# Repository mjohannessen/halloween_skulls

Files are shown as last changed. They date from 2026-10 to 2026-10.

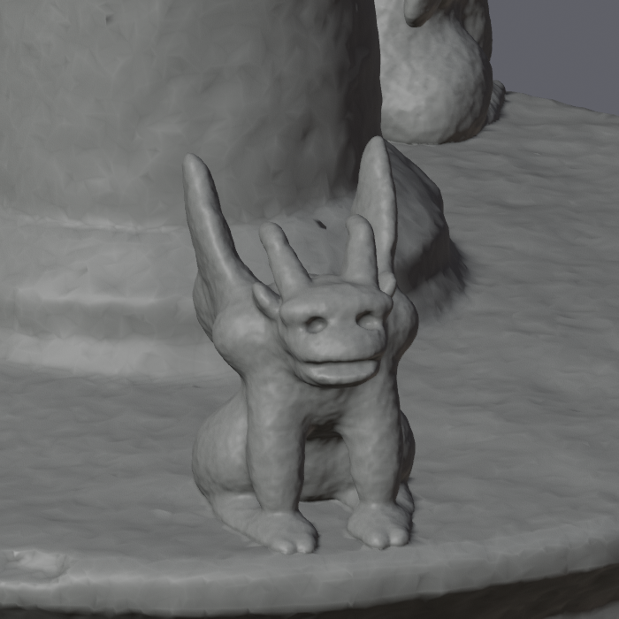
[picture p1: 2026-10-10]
halloween-skull/renders/base_gargoyle.png

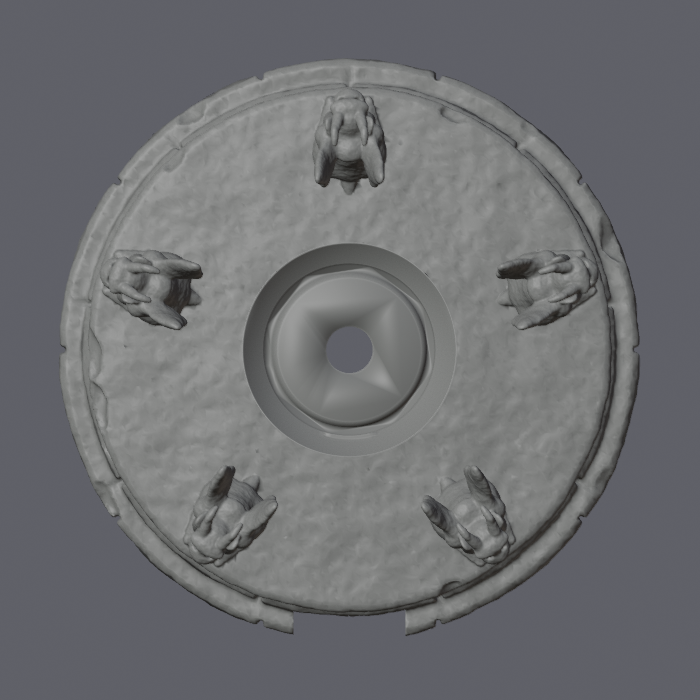
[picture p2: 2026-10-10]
halloween-skull/renders/base_top.png

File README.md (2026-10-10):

# halloween_skulls

3D-printed Halloween ornaments lit by 5V NeoPixels, driven from one control box and controlled from openHAB.

The control box holds a Raspberry Pi Pico W. It has a power input and one output connector, which carries 5V, GND and data out to a chain of **ornaments**. Each ornament has an input and an output connector and holds one or more 5V NeoPixels. Ornaments plug into each other in any order and any mix, and all their LEDs form one NeoPixel chain:

```
control box ─► ornament 1 ─► ornament 2 ─► … ─► ornament N (output unused)
```

The first set of ornaments is three skulls with one LED each:

```
control box ─► skull 1 (1 LED) ─► skull 2 (1 LED) ─► skull 3 (1 LED)
```

## Control box

### Power

The box runs from either a 5V wall brick or a 5V battery pack. Both have DC5521 (5.5 × 2.1 mm) plugs and share one panel jack, one at a time. The Pico's micro-USB stays reachable for flashing.

```
DC jack + ──┬── chain output 5V (1000 µF across 5V / GND)
            │
            ├── 1N5817 Schottky ─────────────────────┬── Pico VSYS ── 74AHCT125 VCC
            │                                        │
            │   micro-USB ── VBUS ── Pico's onboard diode ──┘
            │
            └── 10 kΩ ──┬── GP28 (supply sense)
                        └── 15 kΩ ── GND

DC jack − ── GND (common to the Pico, shifter and chain output)
```

- **The LEDs run straight from the DC jack**, not through the Pico, so the chain's current doesn't pass through the Pico or the diode.
- **The Pico runs from VSYS**, fed through diodes from the jack and from USB. Both can be connected at once without either back-feeding the other. VSYS sits at about 4.7V either way (5V less one diode drop).
- **USB alone doesn't power the chain.** USB is for flashing, so a laptop's USB port never has to supply the LEDs.
- **Supply sense:** a 10 kΩ / 15 kΩ divider puts about 3.0V on GP28 when the jack has power, and the 15 kΩ pulls it to 0V when it doesn't. On USB alone the shifter is still powered from VSYS but the chain isn't, so a high on the data line would feed current into the first LED's data input. The firmware reads GP28 and holds GP0 low unless the jack has power.

### Data

```
Pico GP0 ── 74AHCT125 1A → 1Y ── 330 Ω ── chain output DATA
```

The 74AHCT125 shifts the Pico's 3.3V data up to VSYS, about 4.7V, because 3.3V is below the LEDs' 0.7 × 5V = 3.5V input threshold. Only channel 1 is used. The 330 Ω resistor sits at the shifter's output and protects the first LED's data input.

### Wiring list

Every connection in the box, grouped by net. Pico pin numbers are the physical pins (pin 1 is GP0, next to the USB connector). Do **not** connect anything to the Pico's VBUS (pin 40); the jack feeds VSYS only, through the diode.

| Net | Connects |
|---|---|
| **5V (jack)** | DC jack + (centre pin) · 1N5817 anode · 10 kΩ · 1000 µF + leg · JST output red (5V) |
| **VSYS** | 1N5817 cathode (banded end) · Pico pin 39 (VSYS) · 74AHCT125 pin 14 (VCC) · pin 4 (2OE) · pin 10 (3OE) · pin 13 (4OE) · 0.1 µF |
| **GND** | DC jack − (sleeve) · Pico pin 38 (GND) · 74AHCT125 pin 7 (GND) · pin 1 (1OE) · pin 5 (2A) · pin 9 (3A) · pin 12 (4A) · 15 kΩ · 1000 µF − leg (striped side) · 0.1 µF · JST output GND |
| **Sense** | 10 kΩ · 15 kΩ · Pico pin 34 (GP28 / ADC2) |
| **Data in** | Pico pin 1 (GP0) · 74AHCT125 pin 2 (1A) |
| **Data out** | 74AHCT125 pin 3 (1Y) · 330 Ω |
| **Chain DATA** | 330 Ω · JST output DATA |

74AHCT125 pins 6 (2Y), 8 (3Y) and 11 (4Y) are outputs and stay unconnected. Its enables are active-low, so 1OE to GND turns channel 1 on and 2OE–4OE to VCC turn the unused channels off. The unused inputs go to GND so they don't float.

Build notes:

- **Placement:** the 0.1 µF goes right at the shifter's pins 14 and 7. The 1000 µF goes where the jack and the JST output wires land on the perfboard, so the chain's current doesn't run through the shifter's ground.
- **Wire gauge:** the jack-to-output 5V and GND carry the whole chain's current (up to 2 A on the 2 A brick), so use 22 AWG there. The Pico and signal wires can be thinner.
- **Wires to the Pico:** with the Pico's USB end at the back wall and its pins facing up, pins 34, 38 and 39 are on the edge facing the perfboard. GP0 (pin 1) is on the edge against the side wall, so its wire crosses the USB end of the board.
- **Checks before plugging in ornaments:** with only the jack connected, measure about 5V at the JST output's 5V/GND, about 4.7V at VSYS and at the shifter's pin 14, and about 3.0V at GP28. With only USB connected, the JST output's 5V should read 0V.

## Chain connector

Every connection in the chain is a **JST-SM 3-pin** pigtail pair, the standard WS2812 string connector:

| Wire | Signal |
|---|---|
| Red | 5V |
| Green (or white) | DATA |
| White (or black) | GND |

Wire colours vary between batches. Check the pairs you buy, then use the same pin order everywhere.

- The **box output** and every **ornament output** use the **female** (socket) half, so the live 5V pins are recessed and can't short against anything.
- Every **ornament input** uses the **male** (pin) half.

Any ornament can then plug into the box or into any other ornament. The last ornament's output is still live, so leave its cap on or tape it.

## Ornaments

An ornament is any housing with an input pigtail, one or more 5V NeoPixels in a chain, and an output pigtail:

```
input 5V ───────┬──────────┬──────────────── output 5V
input GND ──────┼────┬─────┼────┬─────────── output GND
input DATA ── DIN LED 1 DOUT ── DIN LED 2 DOUT ── … ── output DATA
            0.1 µF across each LED's 5V / GND
```

- Through-hole NeoPixels (5 mm or 8 mm, WS2812D / PL9823 type) need a 0.1 µF ceramic capacitor across each LED's 5V and GND pins. They have no onboard decoupling. NeoPixels on a PCB or strip already have it.
- 5V and GND run straight through the ornament to its output, so every ornament gets power from the same pair.

### Skull ornament

One 5 mm through-hole NeoPixel sits in the skull's cavity behind the eyes, and its glow comes out through both eye sockets. The input and output pigtails leave through the 18 mm opening in the skull's base.

The skull model (`halloween-skull/build_skull.py`) needs no changes for this. The LED goes in through the base opening, and its light reaches both eyes through the eye-socket bores that open into the cavity.

Each skull sits on a weathered cemetery-stone base (`halloween-skull/build_base.py`, which writes `base.stl`, `base.blend` and `renders/base_*.png` / `assembly_*.png`):

- **Pedestal:** round, 62 mm across and 28.5 mm tall. It has two stepped base courses cut into staggered blocks with mortar joints, a drum with a Gothic lancet niche on each of its four sides, and a projecting cap stone sloping up to the stem. Five crouching winged gargoyles (about 13 mm tall) sit on the cap stone ledge facing outward, one at the front; `GARGOYLES`, `GARGOYLE_R` and `GARGOYLE_SCALE` set their number, position and size. `renders/base_gargoyle.png` is a close-up of one.
- **Stem:** a 20 mm stout stone column on a chamfered base block, flaring at 45° into the seat.
- **Weathering:** the stone is voxel-remeshed and displaced with two scales of noise, and its upper edges are chipped. `SEED` sets the chip pattern, so each skull's base can be different. `WEATHER` sets how rough the surface is. The seat, spigot and wire path are added after weathering, so they stay exact.
- **Seat:** 23 mm across. The skull's underside isn't flat: around its opening it rises from 0.7 mm above the chin plane at the front to about 5 mm at the back. So the seat is cut from the skull model itself (with 0.2 mm clearance for glue) and supports the whole underside. A 16.6 mm spigot, 6 mm tall, fits up into the skull's ~17 mm opening and centres it.
- **Wires:** a 5 mm hole runs down the centre, sized for the LED's four 22 AWG wires (5V, GND, DIN, DOUT), which are glued in place to position the LED inside the skull. Underneath is a 45° cone-shaped cavity for splicing them to the input and output JST pigtails. The pigtails leave through a 12 × 6 mm notch at the back.
- **Printing:** print it as modelled, plinth on the bed, with no supports. Every overhang is 45° or steeper, and the niche tops are pointed arches.

The seat is cut from `skull.blend`, so run `build_skull.py` first if the skull changes, then `build_base.py`:

```sh
Blender -b -P build_skull.py -- <output_dir>
Blender -b -P build_base.py -- <output_dir>
```

Dimensions are mm parameters at the top of `build_base.py`.

## Firmware chain layout

The firmware needs to know which ornaments are in the chain, in order from the box, and how many LEDs each has. It keeps this as a list:

```python
CHAIN = [
    ("skull", 1),
    ("skull", 1),
    ("skull", 1),
]
```

The total LED count is the sum of the counts. Effects address ornaments by position in the list, so a mixed chain needs only this list changed, with no change to the effect code. The plan is to make the layout settable over MQTT, so rearranging ornaments doesn't need a reflash.

## Current budget

Each NeoPixel draws up to about 60 mA at full white and about 20 mA for one colour at full brightness. The firmware should cap brightness so the whole chain stays inside the supply.

| Chain | Worst case (full white) |
|---|---|
| 3 skulls × 1 LED | 0.18 A |
| 20 LEDs | 1.2 A |
| 40 LEDs | 2.4 A |

JST-SM connectors and 22 AWG chain wire are good for about 3 A. Above roughly 30 LEDs, or for long cable runs, inject 5V and GND part way along the chain rather than through every connector.

## Parts list

### Control box

| Part | Qty | Notes |
|---|---|---|
| Raspberry Pi Pico W | 1 | Solder wires directly to it rather than fitting headers |
| 74AHCT125 level shifter, DIP-14 | 1 | 3.3V → 5V data. The wiring list uses its DIP-14 pin numbers |
| 330 Ω resistor | 1 | In series with the data line, at the shifter output |
| 1N5817 (or SS14) Schottky diode | 1 | DC jack + → VSYS |
| 10 kΩ and 15 kΩ resistors | 1 each | Supply-sense divider to GP28 |
| 1000 µF 10V electrolytic capacitor | 1 | Across 5V / GND at the chain output, absorbs inrush when ornaments are plugged in |
| 0.1 µF ceramic capacitor | 1 | Across the 74AHCT125's VCC / GND |
| Perfboard | 1 | Holds the shifter, resistors, diode and capacitors |
| DC5521 (5.5 × 2.1 mm) female panel-mount barrel jack | 1 | Power input. The same jack as lr_light: 10.75 mm thread in an 11.2 mm hole |
| JST-SM 3-pin female pigtail | 1 | Chain output, through the box wall |
| M3 heat-set inserts and M3 × 6 mm screws | 4 each | Lid to corner posts |
| M2 self-tapping screws, ~5 mm | 4 | Pico W to its standoffs |
| Small zip tie | 1 | Anchors the output pigtail inside the box |

### Power

| Part | Qty | Notes |
|---|---|---|
| 5V wall brick, DC5521 plug, ≥2 A | 1 | 2 A covers about 30 LEDs at full white |
| KBT 5V 8 Ah lithium-ion battery pack (DC5521 lead) | 1 | Battery power, as an alternative to the brick. It has a built-in boost converter, so it gives a regulated 5V. Three skulls glowing red (~60 mA plus the Pico) run for days per charge. Charge it with its own charger |
| DC5521 extension lead, male–female | as needed | If the brick's or battery's lead doesn't reach |

### Per skull ornament

| Part | Qty | Notes |
|---|---|---|
| 5 mm through-hole NeoPixel (WS2812D-F5 / PL9823-F5 type) | 1 | Diffused lens looks best |
| 0.1 µF ceramic capacitor | 1 | Across the LED's 5V / GND pins |
| JST-SM 3-pin pigtail pair | 1 | The male half is the input, the female half the output |
| Heat-shrink tubing | — | For the LED leg joints |

### Chain

| Part | Qty | Notes |
|---|---|---|
| JST-SM 3-pin extension lead | as needed | Between ornaments that sit further apart than their pigtails reach |

## Enclosure (`cad/`)

### Control box

`cad/control_box.FCStd` is the control box and its lid. The box is 88.8 × 77 mm outside and 29 mm tall with the lid on. Every dimension is a cell in the document's `Params` spreadsheet, so edit a cell and press Recompute.

- **Inside:** the Pico W sits on four 5 mm standoffs along the left side, with M2 self-tapping screws. The perfboard sits beside it in a floor cradle, 4 mm up for solder-joint clearance, with no screws.
- **Back wall:** everything plugs in here: the micro-USB slot at the Pico's USB end, the DC jack (11.2 mm hole) and a 5 mm hole for the JST-SM output pigtail's wires. A zip-tie anchor on the floor behind the pigtail hole takes the pull off the solder joints.
- **Lid:** a flat plate whose lip drops 3 mm inside the walls to locate it. Four M3 screws hold it on, through counterbored holes into heat-set inserts in the corner posts.
- **Printing:** print the body open side up and the lid flat face down, both without supports.

| File | What it is |
|---|---|
| `control_box.FCStd` | **The model, edit this.** `Control_box_body` and `Control_box_lid` are the printed parts. The `Components` group holds placeholders (Pico, perfboard, jack, pigtail) for checking fit and isn't printed |
| `stl/control_box_body.stl`, `stl/control_box_lid.stl` | Ready-to-print exports. After editing, re-export with File → Export on each part |
| `control_box.py` | Generates the `.FCStd` from scratch. It only overwrites with `SKULL_OVERWRITE=1 freecadcmd control_box.py`, so hand edits aren't lost |

The perfboard size (48.3 × 44.5 mm), the jack's thread (10.75 mm), its body length inside the box (10 mm) and its nut (14 mm) are measured. The perfboard's components are taken as 12 mm tall (`PERF_H`, with the 1000 µF capacitor lying on its side), which leaves about 6 mm under the lid for wiring. Check them against the built board before printing.

### Earlier two-skull design

`cad/skull_bases.FCStd` and `cad/skull_bases.py` are the earlier design: a control base under the master skull, a stand for the second skull and a JST link between them. The control box and the cemetery-stone skull bases replace them. Only the battery box (`Battery_box_body` / `Battery_box_lid`) is still useful.

## Planned: low-battery alert

The battery pack's boost converter holds its output at 5V until the cells are nearly empty and then cuts off. Measuring the supply voltage gives no warning, and the Pico can't tell the battery from the wall brick, since both supply a regulated 5V through the same jack. So:

- **Power source:** openHAB holds a switch (e.g. `Skulls_On_Battery`) that you turn on when the battery is plugged in, and the firmware reads it over MQTT.
- **Charge estimate:** while on battery, the firmware adds up runtime weighted by LED count and brightness against the pack's ~30 Wh. It saves the total to flash every few minutes so it survives restarts. Turning `Skulls_On_Battery` back on after a recharge resets the counter.
- **MQTT:** it publishes something like `skulls/status {"power":"battery","batt_hours":18.5,"batt_pct":62}`. Its last will publishes `offline` on the same topic, following led_flowerpot's command/reply/status pattern.
- **openHAB:** at about 20% left, a rule pushes an ntfy alert. If the skulls go offline while on battery, it pushes "Skulls offline — battery probably dead".

If the estimate turns out to be unreliable, an INA219 current sensor in the control box can measure the mAh actually used.

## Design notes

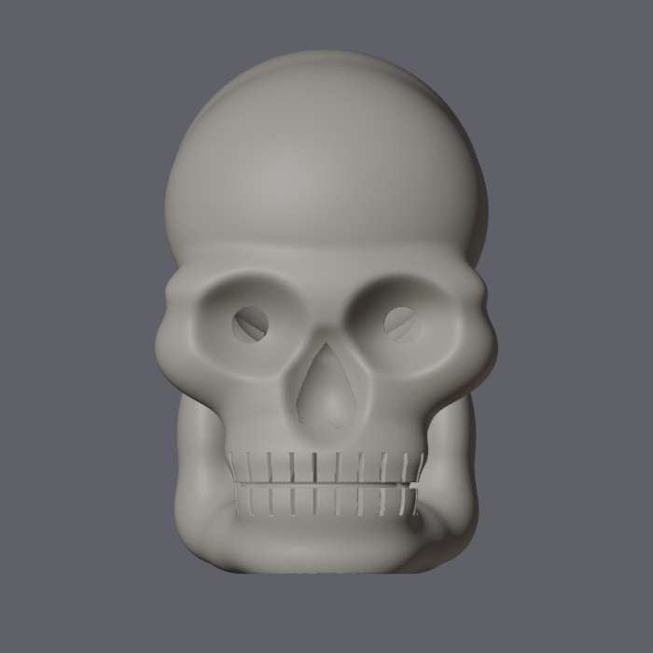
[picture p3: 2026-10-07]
halloween-skull/renders/front.png

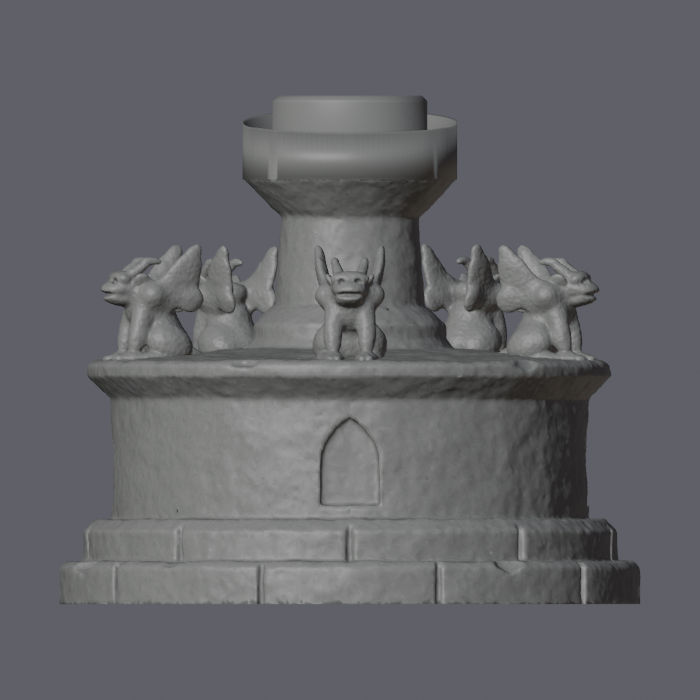
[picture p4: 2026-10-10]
halloween-skull/renders/base_front.png

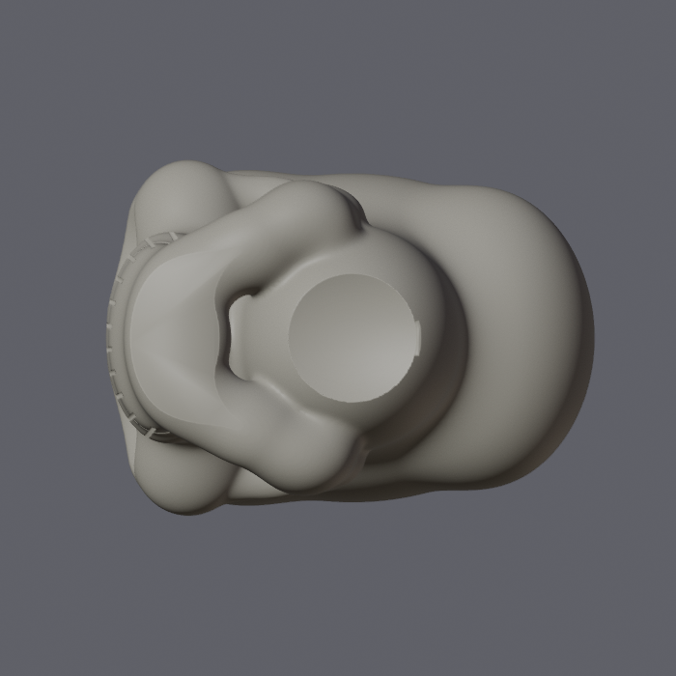
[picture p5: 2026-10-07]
halloween-skull/renders/bottom.png

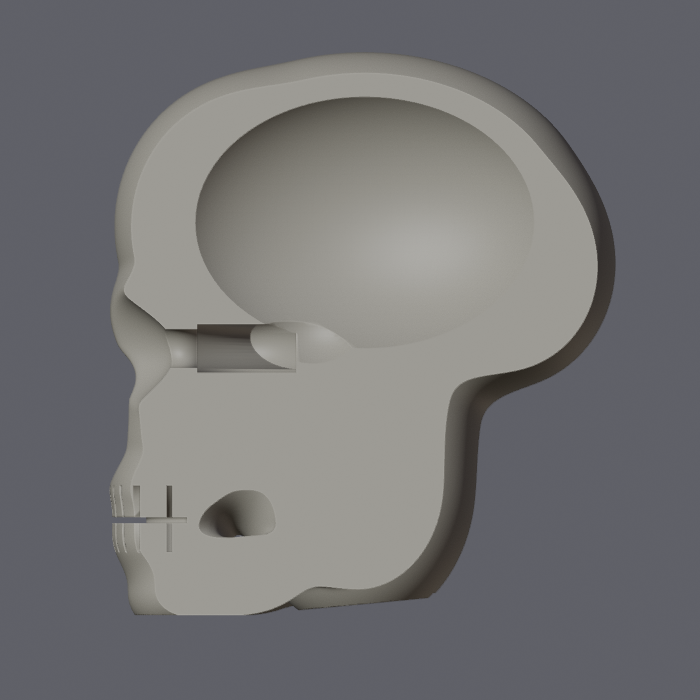
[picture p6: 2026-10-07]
halloween-skull/renders/section_eye.png

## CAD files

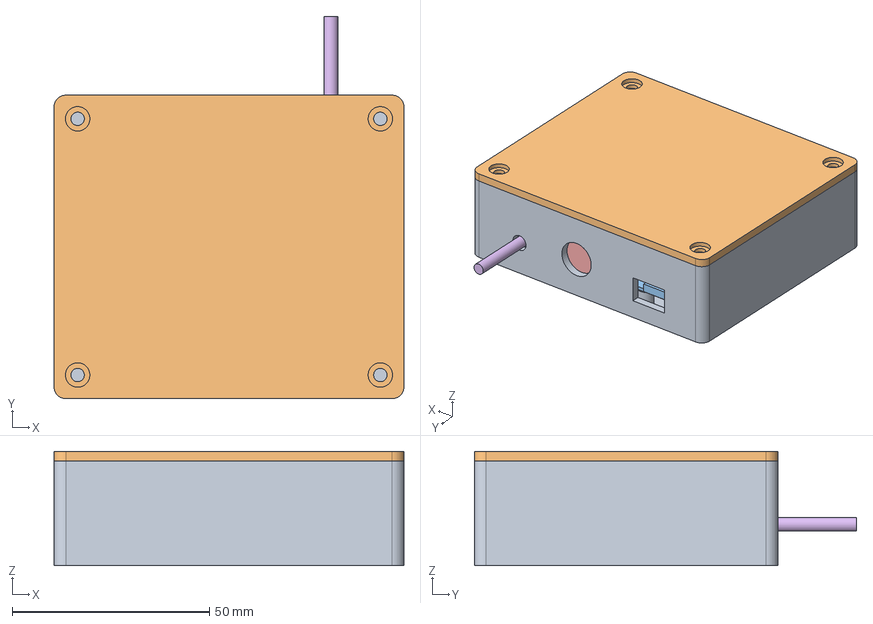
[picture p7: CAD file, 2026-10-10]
cad/control_box.FCStd
88.8 x 97.0 x 29.0 mm
Control_box_body
Control_box_lid
Pico_W
Perfboard
DC_jack
Output_pigtail

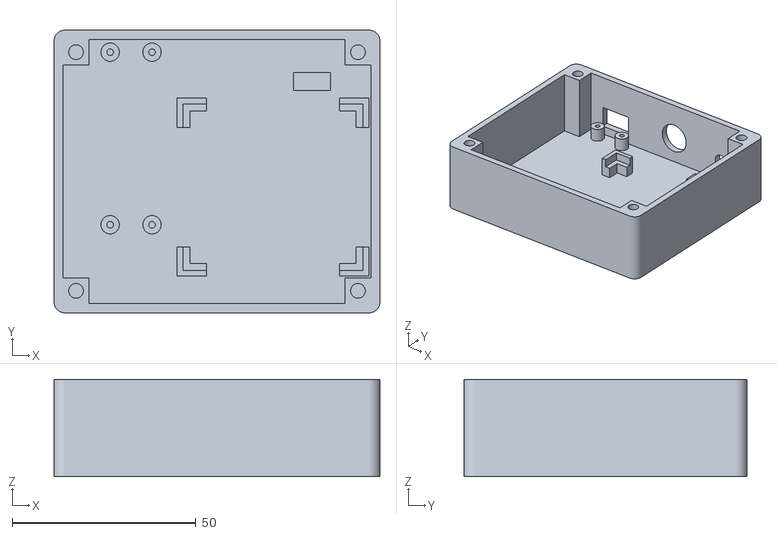
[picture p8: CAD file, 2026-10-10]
cad/stl/control_box_body.stl
88.8 x 77.0 x 26.5

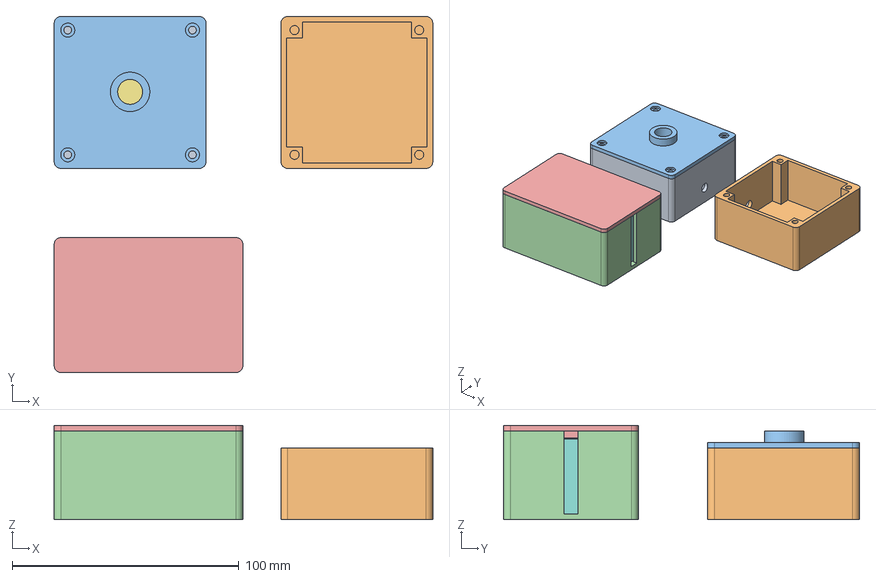
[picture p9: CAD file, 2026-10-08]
cad/skull_bases.FCStd
167.0 x 157.0 x 41.5 mm
Control_base_body
Stand_body
Lid
Battery_box_body
Battery_box_lid
Pico_W
Perfboard
Battery_pack

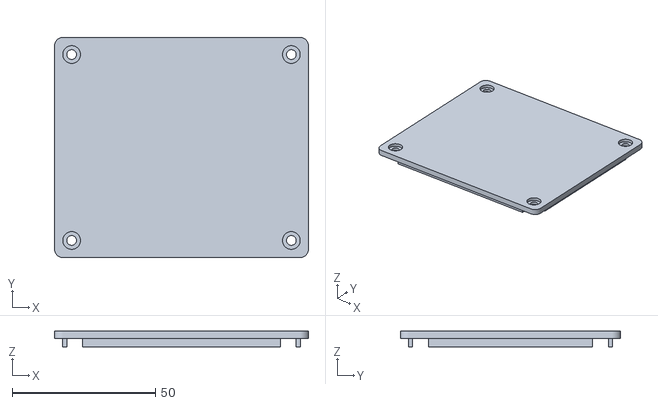
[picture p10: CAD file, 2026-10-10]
cad/stl/control_box_lid.stl
88.8 x 77.0 x 5.50

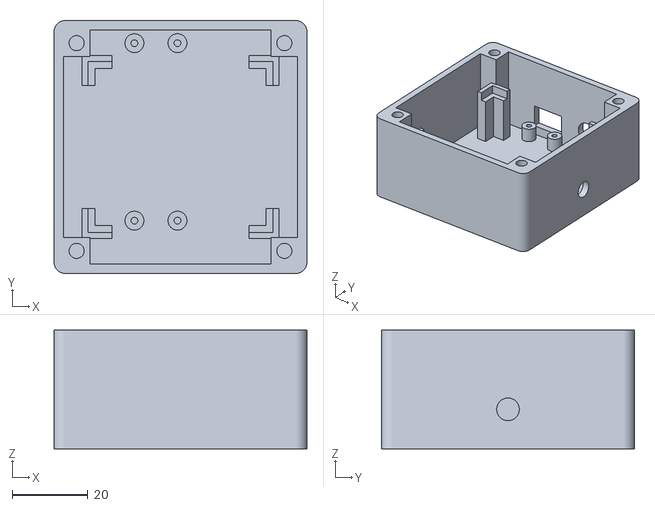
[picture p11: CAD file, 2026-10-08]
cad/stl/control_base_body.stl
67.0 x 67.0 x 31.5

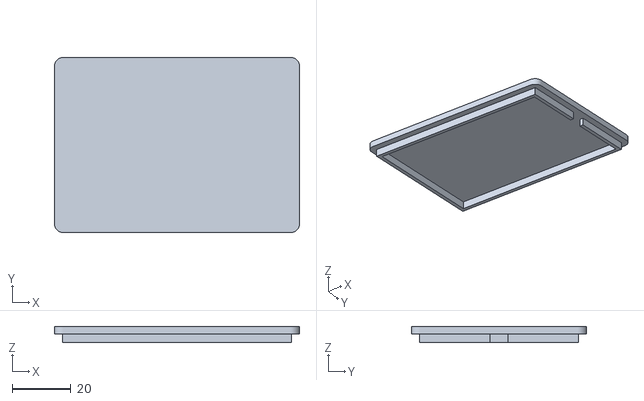
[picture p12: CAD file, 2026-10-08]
cad/stl/battery_box_lid.stl
83.2 x 59.5 x 5.50

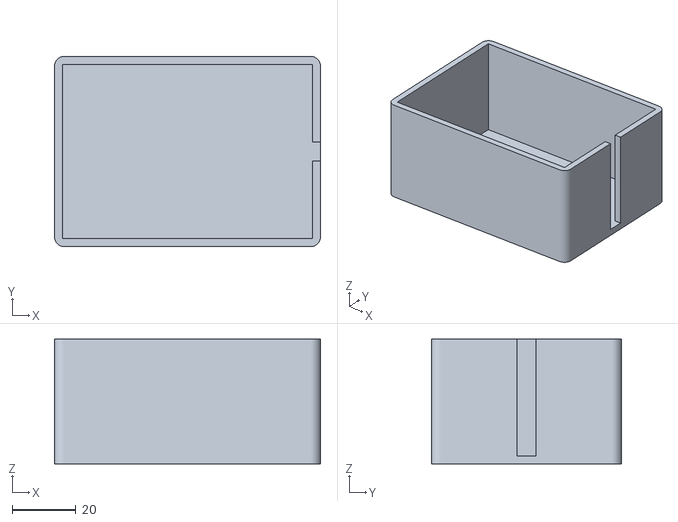
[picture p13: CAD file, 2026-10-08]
cad/stl/battery_box_body.stl
83.2 x 59.5 x 39.0

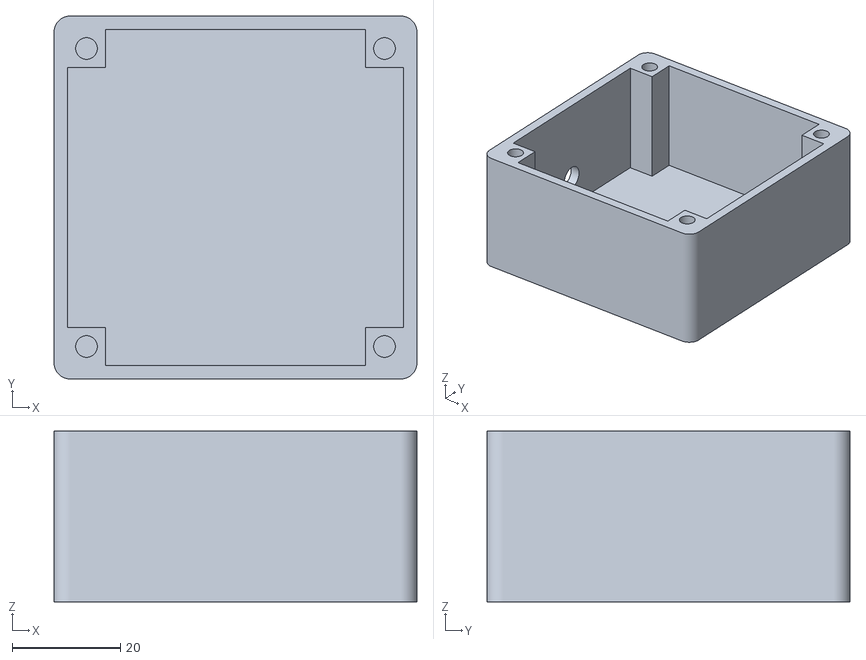
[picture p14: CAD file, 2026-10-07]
cad/stl/stand_body.stl
67.0 x 67.0 x 31.5

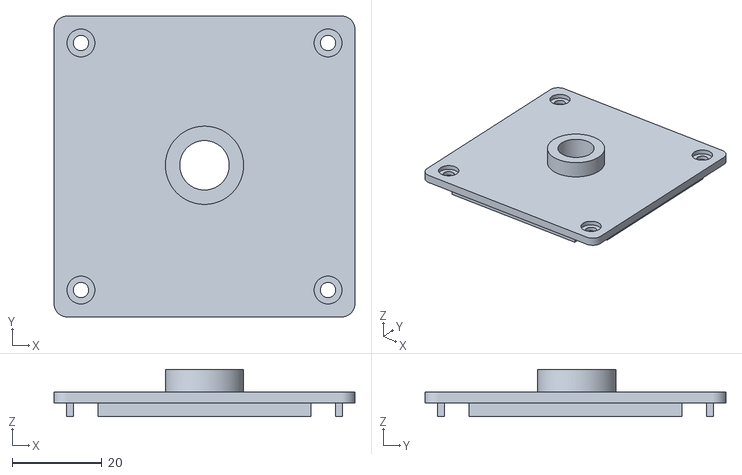
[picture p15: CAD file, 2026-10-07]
cad/stl/lid_x2.stl
67.0 x 67.0 x 10.5

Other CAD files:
halloween-skull/base.blend
halloween-skull/skull.blend

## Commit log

2026-10-07 Add procedural skull model (Blender script, .blend, STL, renders)
    [skull.blend]
2026-10-07 Parametric FreeCAD bases: control base (Pico W), second-skull stand, lid with locating tube
    One Pico W drives all four eyes; a 3-pin JST link carries 5V/GND/data
    to the second skull. README parts list updated for that layout.
    [control_base_body.stl, lid_x2.stl, skull_bases.FCStd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]
2026-10-07 Stack the 48.3 x 44.5 mm perfboard above the Pico W
    Raised corner-bracket cradle centred in the control base, Pico moved
    right to clear it, inside height 24 -> 29 mm. STLs regenerated.
    [control_base_body.stl, lid_x2.stl, skull_bases.FCStd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]
2026-10-08 Battery power: DC5521 jack in the control base, battery box
    The control base takes either USB or a 5 V 8 Ah pack through a back-wall
    DC5521 jack; the pack feeds VSYS via a Schottky diode and the LEDs move
    from VBUS to VSYS. New friction-fit battery box with a lead slot.
    [battery_box_body.stl, battery_box_lid.stl, control_base_body.stl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]
2026-10-08 README: planned low-battery alert over MQTT
2026-10-10 Separate control box and chainable ornaments; cemetery-stone skull base
    README: the Pico W moves to a standalone control box feeding a JST-SM
    chain of ornaments (first set: three one-LED skulls). LEDs run straight
    from the DC jack, VSYS via Schottky, GP28 senses jack power.
    build_base.py generates the weathered stone base (lancet niches, chipped
    edges, metaball gargoyles) with a seat boolean-cut from skull.blend.
    [base.blend]
2026-10-10 Standalone control box and screw-on lid
    Parametric FreeCAD model (cad/control_box.py -> control_box.FCStd):
    Pico W on standoffs beside the perfboard cradle; micro-USB, DC jack (same
    jack as lr_light) and JST-SM output pigtail on the back wall, with a
    zip-tie anchor. Lid locates with a lip and screws to M3 heat-set inserts.
    README: control box section and parts list updates.
    [control_box.FCStd, control_box_body.stl, control_box_lid.stl]
2026-10-10 README: control box wiring list; fix shifter enable pins
2026-10-11 README: control box wiring procedure, test routine and results
    Data on GP22 (pin 29, same edge as VSYS/GND/GP28), 4.7k/4.7k supply-sense
    divider (2.5V), 330-470 ohm data resistor, Pico 2 W. Step-by-step wiring
    and a staged test routine (unpowered, USB only, jack only, both, first
    light), with the breadboard build's measured results: all stages pass,
    GRB skull LEDs, battery pack runs without auto-shutoff.
2026-10-11 Firmware: MicroPython skulls controller over MQTT
    skulls_controller.py (CHAIN-based zones; ON/OFF/COLOR/PATTERN heartbeat|
    flicker|breathe|rainbow/BRIGHTNESS/SET STARTUP; boots OFF; data held low
    without jack power) and net_mqtt.py on skulls/command|reply|status plus
    retained skulls/power. README: firmware, topics, deploy, integration.
2026-10-14 README: openHAB runs the skulls rainbow from dawn to 23:00 like the flowers
2026-10-15 MQTT: ping every 30 s so a session the broker dropped gets noticed
    umqtt.simple never pings, and check_msg() only sees "no data" on a
    half-open socket, so after the broker timed the session out during a
    Wi-Fi drop the Pico stayed offline until power-cycled. The ping provokes
    an RST, the next check_msg() raises, and poll() reconnects. Also close
    the dead session's socket before reconnecting.
